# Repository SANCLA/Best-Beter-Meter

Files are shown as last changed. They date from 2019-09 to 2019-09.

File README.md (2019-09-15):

# Best-Beter-Meter

CO2 en temperatuur monitor

Versie:					03

Datum:				15-9-2019

Ontwikkelbron:		https://github.com/SANCLA/Best-Beter-Meter

Introductie Best Beter Meter

Op kantoor is er soms de behoefte om de luchtkwaliteit inzichtelijk te maken daar deze van grote invloed is op de werkprestaties en algehele gezondheid van aanwezigen. De Best Beter Meter geeft een invulling aan door een van de belangrijkste aspecten te meten, inzichtelijke te maken en te registreren. 
De Best Beter Meter monitort de CO2 en temperatuur waarden en maakt deze toegankelijk inzichtelijk middels een stoplicht feedback. Daarnaast is er, door de registratie op een geheugenkaart, ook een lange termijn trend inzichtelijk te maken.  

Hoewel de luchtkwaliteit door veel meer aspecten beinvloed kan worden dan alleen CO2 en temperatuur, zijn deze waarden relatief eenvoudig te meten en veelal een aanwegezen indicatie van de algehele luchtkwaliteit. 

Meer informatie over de Best Beter Meter vindt je terug in de Handleiding.

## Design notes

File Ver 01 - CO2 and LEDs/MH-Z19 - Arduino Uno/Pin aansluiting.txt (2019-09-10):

MH-Z19		<->		Arduino

Tx		Oranje		A0
Rx		geel		A1
PWM		groen		~9
GND		zwart		GND
Vin		rood		5V

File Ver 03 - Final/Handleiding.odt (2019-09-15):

Best Beter Meter

CO2 en temperatuur monitor

Versie: 03.1
Datum: 15-9-2019

Open Source bron: https://github.com/SANCLA/Best-Beter-Meter

Inhoud

1. Introductie Best Beter Meter

2. Functies en werking

3. CO2 concentraties

4. Registratie op SD kaart

5. Bronnen

Let op! Om de monitor goed te kunnen laten functioneren, plaats de monitor op een minimale afstand van 1 meter van CO2 bronnen (mens of dier) en behoud afstand.

1. Introductie Best Beter Meter

Op kantoor is er soms de behoefte om de luchtkwaliteit inzichtelijk te maken daar deze van grote invloed is op de werkprestaties en algehele gezondheid van aanwezigen. De Open-Source Best Beter Meter geeft hieraan een invulling door een van de belangrijkste aspecten van luchtkwaliteit binnenshuis te meten, deze inzichtelijke te maken en te registreren op een geheugenkaart.

De Best Beter Meter monitort de CO2 en temperatuur waarden en maakt deze toegankelijk en inzichtelijk middels een stoplicht feedback systeem. Daarnaast is er, door de registratie op een geheugenkaart, ook een lange termijn trend inzichtelijk te maken.

Hoewel de luchtkwaliteit door veel meer aspecten beinvloed kan worden dan alleen CO2 en temperatuur, zijn deze waarden relatief eenvoudig te meten en veelal een sterke indicatie van de algehele luchtkwaliteit (of er voldoende ‘frisse’ lucht aanwezig is).

2. Functies en werking

De Best Beter Meter meet elke 10 seconden de CO2 en de temperatuur waarden.

Een gemiddelde van 3 metingen wordt verwerkt, geregistreerd en weergegeven op het LCD display en het LED stoplicht systeem. De meter heeft een vertraging van enkele minuten op haar omgeving.

Omdat de CO2 sensor een zeer gevoelige sensor is het advies om te alle tijden de Beter Best Meter op een afstand van minimaal 1 meter van enig CO2 bron te plaatsen (mensen, dieren, enz). Plaats de meter bijvoorbeeld op een kast uit de buurt van bureau’s.
Plaats de sensor weg van hittebronnen en voorkom blootstelling aan direct zonlicht.

De Best Beter Meter heeft een SD kaart nodig om te kunnen functioneren. Elke 5 minuten worden de gemiddelde waarden weggeschreven naar deze SD kaart, inclusief tijd en datum. Deze waarden worden opgeslagen in een CSV (Comma Seperated value) bestand welke in bijvoorbeeld Microsoft Excel kan worden geimporteerd.

De Best Beter Meter heeft een 4-tal LED’s waarmee de status en de CO2 concentratie kan worden afgelezen, alsmede een LCD display waarop exacte waarden en status zichtbaar zijn.

LED | Status | Resultaat
Blauw | Continue | Fout, zie LCD display…
Blauw | Knippert kort (500 ms) | Intialiseren (duurt ca 3 minuten)
Blauw | Knipprt zeer kort (100 ms) | Wegschrijven meeting naar SD geheugenkaart
Blauw | Knippert lang (1-2 sec) | Meting CO2 en temperatuur waarde
Groen | Continue | CO2 waarde lager dan 1000 PPM
Geel | Continue | CO2 waarde tussen de 1000 PPM en de 1500 PPM
Rood | Continue | CO2 waarde hoger dan 1500 PPM

Gebruikte CO2 sensor: Winsen MH-Z19B [4].
Nauwkeurigheid volgens leverancier: ±(50ppm+3% waarde) [4].
De sensor calibreert automatisch elke 24 uur.

3. CO2 concentraties

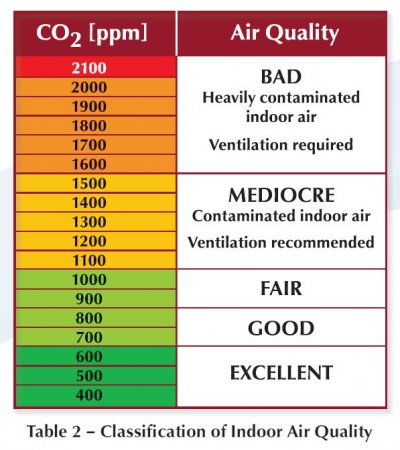
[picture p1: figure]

De World Health Organisation (WHO) heeft helaas geen aanbevelingen gepubliceerd over CO2 concentraties binnenshuis en de effecten hiervan. Wel een publicatie voor het tot stand komen van een algemene standaard [1], echter is het WHO hier nog niet zover mee. De WHO heeft enkele aanbevelingen en publicaties op haar website gepubliceerd op een aantal andere facetten van luchtkwaliteit en “Indoor Air Quality (IAQ)”. De Nederlandse overheid heeft hier echter niet concreets gepubliceerd, anders dan dat er voldoende luchtverversing plaats dient te vinden [3].

Binnen Europa is de standaard maximaal 3.500 PPM blootstelling voor een normale werkdag. Binnen het Verenigd Koninkrijk is het advies voor scholen een maximale bloodstelling van 1.500 PPM. De Verenigde Staten adviseerd als maximaal blootstelling een waarde van 5.000 PPM. Het varieert dus nogal wat goede en wat slechte waarden zijn. Wel is iedereen er het in grote lijnen over eens dat het goed is om te gaan ventileren bij waarden boven de 1.000 PPM [2].

Ter indicatie kan men de weergegeven tabel aanhouden, als maatstaaf voor het beoordelen van de metingen en waarden. Het LED stoplicht systeem van de Best Beter Meter is hierop gebasseerd.

4. Registratie op SD kaart

Elke keer als de Best Beter Meter wordt opgestart zal deze, omhoog nummerend, een nieuw registratiebestand aanmaken op de SD geheugenkaart genaamd “LOGGER001.CSV”. Tot 100 registratiebestanden worden automatisch aangemaakt, daarna wordt het eerste registratiebestand weer overschreven. Elke 5 minuten wordt er een registratie van de actuele CO2 en temperatuur waarden naar de SD geheugenkaart weggeschreven.

In het registratiebestand worden de navolgende zaken in CSV (Comma Seperated Value) formaat opgenomen:

Veld | Voorbeeld | Omschrijving
msrunning | 1237064431 | Aantal miliseconden dat de Best Beter Meter actief is sinds de laatste herstart
unixtime | 1568559342 | Datum/Tijd van registratie in het UNIX time format
datetime | 2019/9/15 14:54:31 | Datum/Tijd van registratie in het volgende format: jaar/maand/dag uur:minuten:seconden
co2uart | 988 | CO2 waarde (gemiddelde van 3 metingen)
temp | 21 | Temperatuur waarde (gemiddelde van 3 metingen)

De SD kaart dient in het FAT16 of FAT32 bestandsformaat geformateerd te zijn.

Als tijdens het actief zijn van de Best Beter Meter de SD kaart onverwacht wordt verwijderd kan er corruptie onstaan in het registratiebestand en zal de registratie van metingen op de SD kaart stoppen totdat de Best Beter Meter opnieuw wordt opgestart.

5. Bronnen

[1] http://www.euro.who.int/__data/assets/pdf_file/0007/78613/AIQIAQ_mtgrep_Bonn_Oct06.pdf

[2] https://en.wikipedia.org/wiki/Carbon_dioxide

[3] https://www.arboportaal.nl/onderwerpen/luchtverversing
[4] https://www.winsen-sensor.com/d/files/infrared-gas-sensor/mh-z19b-co2-ver1_0.pdf

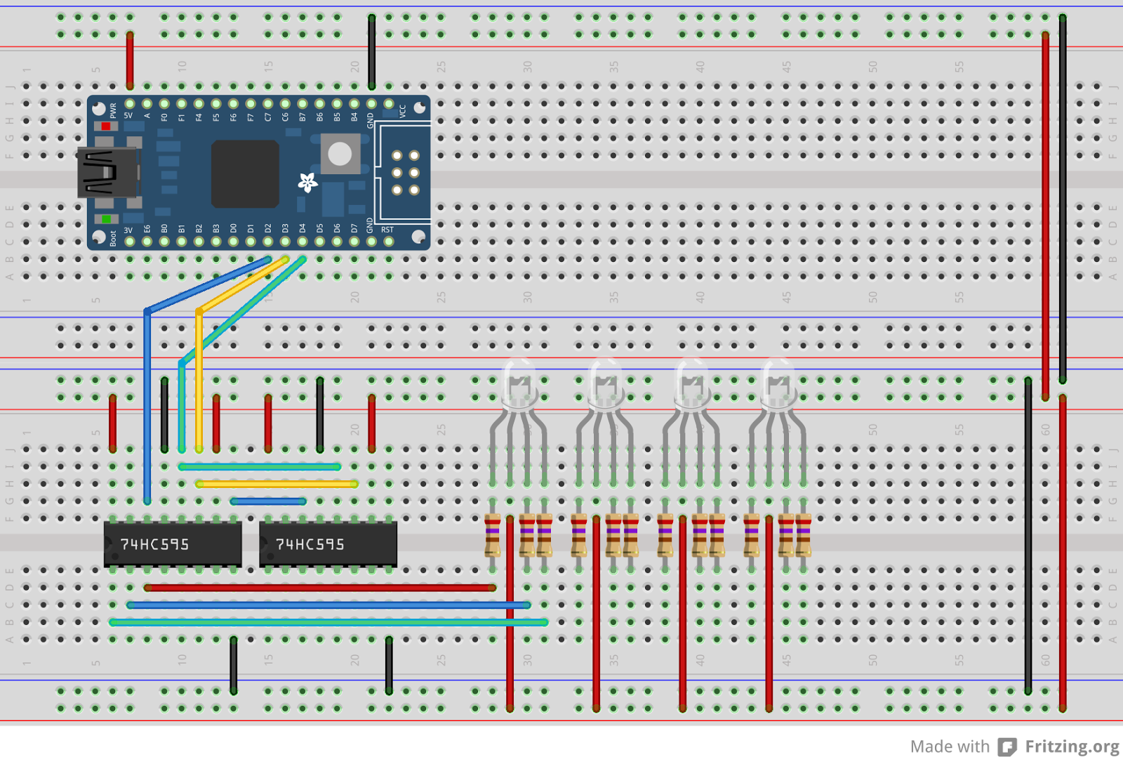
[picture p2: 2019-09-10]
proxy.duckduckgo.com.png

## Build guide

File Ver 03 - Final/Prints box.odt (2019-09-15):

Best Beter Meter

CO2 en temperatuur monitor

Status

CO2 - Minder dan 1000 PPM

CO2 - 1000 tot 1500 PPM

CO2 - Meer dan 1500 PPM

https://github.com/SANCLA/Best-Beter-Meter

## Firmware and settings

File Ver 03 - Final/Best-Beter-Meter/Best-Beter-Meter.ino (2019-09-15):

#include <SoftwareSerial.h>
#include <SPI.h>
#include <SD.h>
#include <Wire.h>
#include "RTClib.h"
#include <LiquidCrystal_I2C.h>

LiquidCrystal_I2C lcd(0x27, 20, 4); // set the LCD address to 0x27 for a 16 chars and 2 line display

#define ECHO_TO_SERIAL   1 // echo data to serial port

SoftwareSerial co2Serial(A0, A1); // define MH-Z19 RX TX
unsigned long startTime = millis();

const byte PINtoRESET = 8; // reset pin
const byte ledPinStatus = 7; //Blue led
const byte ledPinGreen = 6; //Green led
const byte ledPinYellow = 5; //Yellow led
const byte ledPinRed = 4; //Red led
const byte chipSelect = 10;
int watchdog_uart_ppm;
int co2ppm_average;
int co2ppm_average_1;
int co2ppm_average_2;
int co2ppm_average_3;
byte watchdog_temp;
byte count;
int measure_every_ms = 10000; // 10000 = 10 seconds
unsigned long log_every_ms = 300000; // 300000 = 5 minutes
byte write_to_log = 0;
unsigned long write_to_log_counter = 0;

RTC_DS1307 RTC;

// the logging file
File logfile;

void error(char *str)
{
  Serial.print("error: ");
  Serial.println(str);

  while (1);
}

void setup() {
  digitalWrite(PINtoRESET, LOW);
  Serial.begin(9600);
  co2Serial.begin(9600);
 // pinMode(9, INPUT);
  pinMode(ledPinStatus, OUTPUT);
  pinMode(ledPinGreen, OUTPUT);
  pinMode(ledPinYellow, OUTPUT);
  pinMode(ledPinRed, OUTPUT);

  Serial.println("Initializing SD card...");
  pinMode(10, OUTPUT);
  while (!SD.begin(chipSelect)) {
    lcd.init();
    // Print a message to the LCD.
    lcd.backlight();
    lcd.setCursor(0, 0);
    lcd.print("ERROR !");
    lcd.setCursor(0, 1);
    lcd.print("INSERT SD CARD...");
    //    error("Card failed, or not present");
    digitalWrite(ledPinStatus, HIGH);
  }
  Serial.println("card initialized.");

  // create a new file
  char filename[] = "LOGGER00.CSV";
  for (uint8_t i = 0; i < 100; i++) {
    filename[6] = i / 10 + '0';
    filename[7] = i % 10 + '0';
    if (! SD.exists(filename)) {
      // only open a new file if it doesn't exist
      logfile = SD.open(filename, FILE_WRITE);
      break;  // leave the loop!
    }
  }

  if (! logfile) {
    error("couldnt create file");
  }

  Serial.print("Logging to: ");
  Serial.println(filename);

  // connect to RTC
  Wire.begin();
  if (!RTC.begin()) {
    logfile.println("RTC failed");
#if ECHO_TO_SERIAL
    Serial.println("RTC failed");
#endif  //ECHO_TO_SERIAL
  }

  //if (! RTC.isrunning()) {
  //  Serial.println("RTC is NOT running!");
  //  RTC.adjust(DateTime(F(__DATE__), F(__TIME__)));
  //}


  logfile.println("msrunning,unixtime,datetime,co2uart,temp");
#if ECHO_TO_SERIAL
  Serial.println("msrunning,unixtime,datetime,co2uart,temp");
#endif //ECHO_TO_SERIAL

  lcd.init();                      // initialize the lcd
  // Print a message to the LCD.
  lcd.backlight();
  lcd.setCursor(0, 0);
  lcd.print("Best Beter Meter");
  lcd.setCursor(0, 1);
  lcd.print("Initialiseren...");

  Serial.println("Heating up the sensor for 180 seconds...");
  count = 180;
  while (count > 0 )                                  // repeat until count is no longer greater than zero
  {
    digitalWrite(ledPinStatus, HIGH);
    delay(500);
    digitalWrite(ledPinStatus, LOW);
    delay(500);
    count = count - 1;                                 // decrement count
  }
  digitalWrite(ledPinStatus, LOW);
}

void(* resetFunc) (void) = 0; //declare reset function @ address 0

void loop(void) {
  DateTime now;
  if (write_to_log_counter == (log_every_ms - measure_every_ms)) {
    Serial.println("WRITING TO LOG");
    write_to_log = 1;
    write_to_log_counter = 0;
  } else {
    write_to_log = 0;
    write_to_log_counter = write_to_log_counter + (measure_every_ms);
  }
  uint32_t m = millis();
  if (write_to_log == 1) {
    logfile.print(m);           // milliseconds since start
    logfile.print(",");
  }
#if ECHO_TO_SERIAL
  Serial.print(m);         // milliseconds since start
  Serial.print(",");
#endif


  // fetch the time
  now = RTC.now();

  if (write_to_log == 1) {
    // log time
    logfile.print(now.unixtime()); // seconds since 1/1/1970
    logfile.print(",");
    //logfile.print('"');
    logfile.print(now.year(), DEC);
    logfile.print("/");
    logfile.print(now.month(), DEC);
    logfile.print("/");
    logfile.print(now.day(), DEC);
    logfile.print(" ");
    logfile.print(now.hour(), DEC);
    logfile.print(":");
    logfile.print(now.minute(), DEC);
    logfile.print(":");
    logfile.print(now.second(), DEC);
    //logfile.print('"');
  }
#if ECHO_TO_SERIAL
  Serial.print(now.unixtime()); // seconds since 1/1/1970
  Serial.print(",");
  //Serial.print('"');
  Serial.print(now.year(), DEC);
  Serial.print("/");
  Serial.print(now.month(), DEC);
  Serial.print("/");
  Serial.print(now.day(), DEC);
  Serial.print(" ");
  Serial.print(now.hour(), DEC);
  Serial.print(":");
  Serial.print(now.minute(), DEC);
  Serial.print(":");
  Serial.print(now.second(), DEC);
  //Serial.print('"');
#endif //ECHO_TO_SERIAL

  digitalWrite(ledPinStatus, HIGH);
  int ppm_uart = readCO2UART();

  if (co2ppm_average >= 0 && co2ppm_average < 1000) {
    //    Serial.println("LED: GREEN SOLID");
    digitalWrite(ledPinGreen, HIGH);
    digitalWrite(ledPinYellow, LOW);
    digitalWrite(ledPinRed, LOW);
    digitalWrite(ledPinStatus, LOW);
    delay(measure_every_ms);
  } else if (co2ppm_average >= 1000 && co2ppm_average < 1500) {
    //    Serial.println("LED: YELLOW SOLID");
    digitalWrite(ledPinGreen, LOW);
    digitalWrite(ledPinYellow, HIGH);
    digitalWrite(ledPinRed, LOW);
    digitalWrite(ledPinStatus, LOW);
    delay(measure_every_ms);
  } else if (co2ppm_average >= 1500) {
    //   Serial.println("LED: RED");
    digitalWrite(ledPinGreen, LOW);
    digitalWrite(ledPinYellow, LOW);
    digitalWrite(ledPinRed, HIGH);
    digitalWrite(ledPinStatus, LOW);
    delay(measure_every_ms);
  }
  if (write_to_log == 1) {
    logfile.println();
  }
#if ECHO_TO_SERIAL
  Serial.println();
#endif // ECHO_TO_SERIAL

  if ((watchdog_uart_ppm < 0) || (watchdog_uart_ppm > 5000) || (watchdog_temp > 70)) {
    digitalWrite(ledPinGreen, LOW);
    digitalWrite(ledPinYellow, LOW);
    digitalWrite(ledPinRed, LOW);
    digitalWrite(ledPinStatus, HIGH);
    delay(3000);
    lcd.setCursor(0, 0);
    lcd.print("Sensor error !  ");
    delay(1000);
    count = 30;
    while (count > 0) {
      lcd.setCursor(0, 1);
      lcd.print("                ");
      lcd.setCursor(0, 1);
      lcd.print("Reset in ");
      lcd.setCursor(10, 1);
      lcd.print(count);
      lcd.setCursor(12, 1);
      lcd.print("s...");
      delay(1000);
      count = count - 1;
    }
    //pinMode(PINtoRESET, OUTPUT);
      resetFunc();  //call reset
  }

  if (write_to_log == 1) {
    logfile.flush();
    count = 10;
    while (count > 0 )                                  // repeat until count is no longer greater than zero
    {
      digitalWrite(ledPinStatus, HIGH);
      delay(100);
      digitalWrite(ledPinStatus, LOW);
      delay(100);
      count = count - 1;                                  // decrement count
    }
  }
}
int readCO2UART() {
  byte cmd[9] = {0xFF, 0x01, 0x86, 0x00, 0x00, 0x00, 0x00, 0x00, 0x79};
  byte response[9]; // for answer

  //  Serial.println("Sending CO2 request...");
  co2Serial.write(cmd, 9); //request PPM CO2

  // clear the buffer
  memset(response, 0, 9);
  int i = 0;
  while (co2Serial.available() == 0) {
    //    Serial.print("Waiting for response ");
    //    Serial.print(i);
    //    Serial.println(" s");
    delay(1000);
    i++;
  }
  if (co2Serial.available() > 0) {
    co2Serial.readBytes(response, 9);
  }
  // print out the response in hexa
  for (int i = 0; i < 9; i++) {
  }
  byte check = getCheckSum(response);
  if (response[8] != check) {
  }

  // ppm
  int ppm_uart = 256 * (int)response[2] + response[3];
  // temp
  byte temp = response[4] - 40;

  co2ppm_average_3 = co2ppm_average_2;
  co2ppm_average_2 = co2ppm_average_1;
  co2ppm_average_1 = ppm_uart;
  co2ppm_average = ((co2ppm_average_1 + co2ppm_average_2 + co2ppm_average_3)/3);

  // Correction temperature due to boxed sensor combined with SOC (no mechanical airflow)
  temp = temp - 5;
 
  if (write_to_log == 1) {
    logfile.print(",");
    logfile.print(co2ppm_average);
    logfile.print(",");
    logfile.print(temp);
  }
#if ECHO_TO_SERIAL
  Serial.print(",");
  Serial.print("(");
  Serial.print(co2ppm_average_1);
  Serial.print("+");
  Serial.print(co2ppm_average_2);
  Serial.print("+");
  Serial.print(co2ppm_average_3);
  Serial.print(")=average:");
  Serial.print(co2ppm_average);
  Serial.print(",");
  Serial.print(temp);
#endif //ECHO_TO_SERIAL

  watchdog_uart_ppm = ppm_uart;
  watchdog_temp = temp;

  lcd.clear();
  lcd.setCursor(0, 0);
  lcd.print("CO2 : ");
  lcd.print(co2ppm_average);
  lcd.print(" PPM");
  lcd.setCursor(0, 1);
  lcd.print("Temp: ");
  lcd.print(temp);
  lcd.print("\337C");

  // status
  byte status = response[5];
  //  Serial.print("Status? ");
  //  Serial.println(status);
  if (status == 0x40) {
    //    Serial.println("Status OK");
  }
  return ppm_uart;


}

byte getCheckSum(char *packet) {
  byte i;
  unsigned char checksum = 0;
  for (i = 1; i < 8; i++) {
    checksum += packet[i];
  }
  checksum = 0xff - checksum;
  checksum += 1;
  return checksum;
}

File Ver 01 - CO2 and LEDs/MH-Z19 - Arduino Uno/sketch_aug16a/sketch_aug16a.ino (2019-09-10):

#include <SoftwareSerial.h>
SoftwareSerial co2Serial(A0, A1); // define MH-Z19 RX TX
unsigned long startTime = millis();

int ledPinBlue = 4; //Blue led
int ledPinGreen = 5; //Green led
int ledPinYellow = 6; //Yellow led
int ledPinRed = 7; //Red led
int lastppmvalue;
int count;
 
void setup() {
  Serial.begin(9600);
  co2Serial.begin(9600);
  pinMode(9, INPUT);
  pinMode(ledPinBlue, OUTPUT);
  pinMode(ledPinGreen, OUTPUT);
  pinMode(ledPinYellow, OUTPUT);
  pinMode(ledPinRed, OUTPUT);

  digitalWrite(ledPinGreen, HIGH);
  digitalWrite(ledPinYellow, HIGH);
  digitalWrite(ledPinRed, HIGH);
  digitalWrite(ledPinBlue, HIGH);
  delay(1000);
  digitalWrite(ledPinGreen, LOW);
  digitalWrite(ledPinYellow, LOW);
  digitalWrite(ledPinRed, LOW);
  digitalWrite(ledPinBlue, LOW);
  delay(1000);

  count = 30;
    while(count > 0 )                                   // repeat until count is no longer greater than zero
      {
        digitalWrite(ledPinBlue, HIGH);
        delay(500);
        digitalWrite(ledPinBlue, LOW);  
        delay(500);  
        count = count -1;                                  // decrement count
      } 
}
 
void loop() {
  digitalWrite(ledPinBlue, HIGH);
  Serial.println("------------ START ------------");
  Serial.print("Time from start: ");
  Serial.print((millis() - startTime) / 1000);
  Serial.println(" s");
  int ppm_uart = readCO2UART();
  int ppm_pwm = readCO2PWM();

  if (lastppmvalue < 1000) {
    Serial.println("LED: GREEN SOLID");
    digitalWrite(ledPinGreen, HIGH);
    digitalWrite(ledPinYellow, LOW);
    digitalWrite(ledPinRed, LOW);
    digitalWrite(ledPinBlue, LOW);
    delay(10000);
  } else if (lastppmvalue >= 1000 && lastppmvalue < 2000) {
    Serial.println("LED: YELLOW SOLID");
    digitalWrite(ledPinGreen, LOW);
    digitalWrite(ledPinYellow, HIGH);
    digitalWrite(ledPinRed, LOW);
    digitalWrite(ledPinBlue, LOW);
    delay(10000);
  } else if (lastppmvalue >= 2000 && lastppmvalue < 3000) {
    Serial.println("LED: YELLOW BLINKING");
    digitalWrite(ledPinGreen, LOW);
    digitalWrite(ledPinRed, LOW);
    digitalWrite(ledPinBlue, LOW);
    count = 10;
    while(count > 0 )                                   // repeat until count is no longer greater than zero
      {
        digitalWrite(ledPinYellow, HIGH);
        delay(500);
        digitalWrite(ledPinYellow, LOW);  
        delay(500);  
        count = count -1;                                  // decrement count
      } 
  } else if (lastppmvalue >= 3000) {
    Serial.println("LED: RED");
    digitalWrite(ledPinGreen, LOW);
    digitalWrite(ledPinYellow, LOW);
    digitalWrite(ledPinBlue, LOW);
    count = 10;
    while(count > 0 )                                   // repeat until count is no longer greater than zero
      {
        digitalWrite(ledPinRed, HIGH);
        delay(500);
        digitalWrite(ledPinRed, LOW);  
        delay(500);  
        count = count -1;                                  // decrement count
      } 
  } else {
    Serial.println("LED: Ke?");
    digitalWrite(ledPinGreen, HIGH);
    digitalWrite(ledPinYellow, HIGH);
    digitalWrite(ledPinRed, HIGH);
    digitalWrite(ledPinBlue, LOW);
    delay(10000);    
  }
}

int readCO2UART(){
  byte cmd[9] = {0xFF,0x01,0x86,0x00,0x00,0x00,0x00,0x00,0x79};
  byte response[9]; // for answer

  Serial.println("Sending CO2 request...");
  co2Serial.write(cmd, 9); //request PPM CO2

  // clear the buffer
  memset(response, 0, 9);
  int i = 0;
  while (co2Serial.available() == 0) {
//    Serial.print("Waiting for response ");
//    Serial.print(i);
//    Serial.println(" s");
    delay(1000);
    i++;
  }
  if (co2Serial.available() > 0) {
      co2Serial.readBytes(response, 9);
  }
  // print out the response in hexa
  for (int i = 0; i < 9; i++) {
    Serial.print(String(response[i], HEX));
    Serial.print("   ");
  }
  Serial.println("");

  // checksum
  byte check = getCheckSum(response);
  if (response[8] != check) {
    Serial.println("Checksum not OK!");
    Serial.print("Received: ");
    Serial.println(response[8]);
    Serial.print("Should be: ");
    Serial.println(check);
  }
 
  // ppm
  int ppm_uart = 256 * (int)response[2] + response[3];
  Serial.print("PPM UART: ");
  Serial.println(ppm_uart);
  lastppmvalue = ppm_uart;
  // temp
  byte temp = response[4] - 40;
  Serial.print("Temperature? ");
  Serial.println(temp);

  // status
  byte status = response[5];
  Serial.print("Status? ");
  Serial.println(status);
  if (status == 0x40) {
    Serial.println("Status OK");
  }
  return ppm_uart;
}

byte getCheckSum(char *packet) {
  byte i;
  unsigned char checksum = 0;
  for (i = 1; i < 8; i++) {
    checksum += packet[i];
  }
  checksum = 0xff - checksum;
  checksum += 1;
  return checksum;
}

int readCO2PWM() {
  unsigned long th, tl, ppm_pwm = 0;
  do {
    th = pulseIn(9, HIGH, 1004000) / 1000;
    tl = 1004 - th;
    ppm_pwm = 5000 * (th-2)/(th+tl-4);
  } while (th == 0);
  Serial.print("PPM PWM: ");
  Serial.println(ppm_pwm);
  Serial.println("------------ END ------------");
  return ppm_pwm; 
}
